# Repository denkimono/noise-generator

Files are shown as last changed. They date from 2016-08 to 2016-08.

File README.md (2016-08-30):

# Entropy in your pocket!

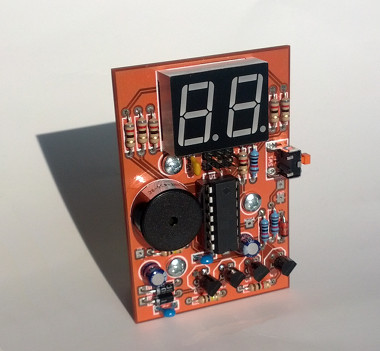
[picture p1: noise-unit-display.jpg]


This is a random number generator but rather than using an algorithm to create only pseudo-random numbers it uses the noise generated by billions of electrons smashing into silicon atoms. This noise is then processed to give a uniform distribution of numbers from 0 to 99 which appears on the display. In addition a speaker on the device enables the noise to be heard. By loading different software onto the device, the numbers can be sent to a computer via a serial link (TTL levels)

## How it works

The noise is generated by applying a reverse voltage to the base-emitter (P-N) junction of a transistor. Normally a P-N junction resists the flow of current in the reverse direction, but if the voltage is high enough then the electrons have enough energy to knock other electrons out of their silicon atoms. These electrons are themselves accelerated by the electric field and knock more electrons out. The process continues and the junction begins to conduct. This effect is called avalanche breakdown.

This generates random voltage fluctuations in the circuit which are amplified and sampled by the microcontroller. Although the noise forms a Gaussian-like distribution of sample values, the probability of an even sample is equal to the probability of an odd sample, so by taking the least significant bits of consecutive samples a flat (uniform) distribution of values can be obtained.

The device is designed to run off a PP3 9V battery (not included).

## How to build it

The file 'bom.txt' contains the parts list and a link to buy them (although these aren't the only sources of these components)

The folder 'gerber' contains all the CAD files you need to make the PCB - just send them off to your favourite board house!

The folder 'code' contains the software to be loaded on to the microcontroller. Type 'make' to build and 'make program' to load it onto the microcontroller using avrdude.

The file 'assembly-instructions.pdf' tells you how to put it together.

Example video of the finished article here:

Noise generator demo (https://www.youtube.com/watch?v=ZSrrZK398-U)

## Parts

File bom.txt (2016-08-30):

1 x PP3 battery holder (flying leads)
https://www.rapidonline.com/trupower-bh9va-pp3-battery-holder-with-flying-leads-18-0163

1 x dual 7 segment display 
https://www.rapidonline.com/truopto-osl20561-ira-14-2mm-dual-red-display-anode-100mcd-57-0151

2 x 1N4001 diodes 
https://www.rapidonline.com/diotec-1n4001-rectifier-diode-1a-50v-50-0381

1 x ATTINY44 
https://www.rapidonline.com/atmel-attiny45-20pu-8bit-microcontroller-4k-flash-dil8-73-4350

1 x row of six PCB pins (for the programming interface)
https://www.rapidonline.com/truconnect-single-row-header-36-way-pcb-plug-22-0545

4 x NPN transistors (BC549C)
https://www.rapidonline.com/diotec-bc549c-npn-transistor-to92-0-2a-30v-50-0298

1 x 5.6V zener diode 
https://www.rapidonline.com/trusemi-bzx55c5v6-zener-diode-0-5w-do35-5-6v-47-3854

3 x screws
https://www.rapidonline.com/affix-pozi-pan-head-self-tapping-screws-no-4-6-5mm-pack-of-100-33-3150

1 x button
https://www.rapidonline.com/omron-b3f-3155-6x6mm-6-15mm-260gf-sq-tact-switch-r-a-78-0140

1 x 14 pin DIL socket
https://www.rapidonline.com/truconnect-ds1009-14-at1nx-14pin-dil-socket-7-62mm-no-central-support-tube-of-34-22-0108

3 x 100nF capacitors 
http://uk.farnell.com/multicomp/mcrr50104z5um0050/cap-cer-z5u-100nf-50v-rad/dp/1216445

2 x 10uF capacitors 
http://uk.farnell.com/multicomp/mcmr63v106m6-3x7/cap-alu-elec-10uf-63v-rad/dp/1870986

1 x speaker
http://uk.farnell.com/pro-signal/abt-436-rc/piezo-transducer-pcb/dp/1300026

Resistors all 0.25W 5% carbon film
3 x 10k resistor 
7 x 82R resistor 
2 x 100k resistor 
1 x 1k resistor

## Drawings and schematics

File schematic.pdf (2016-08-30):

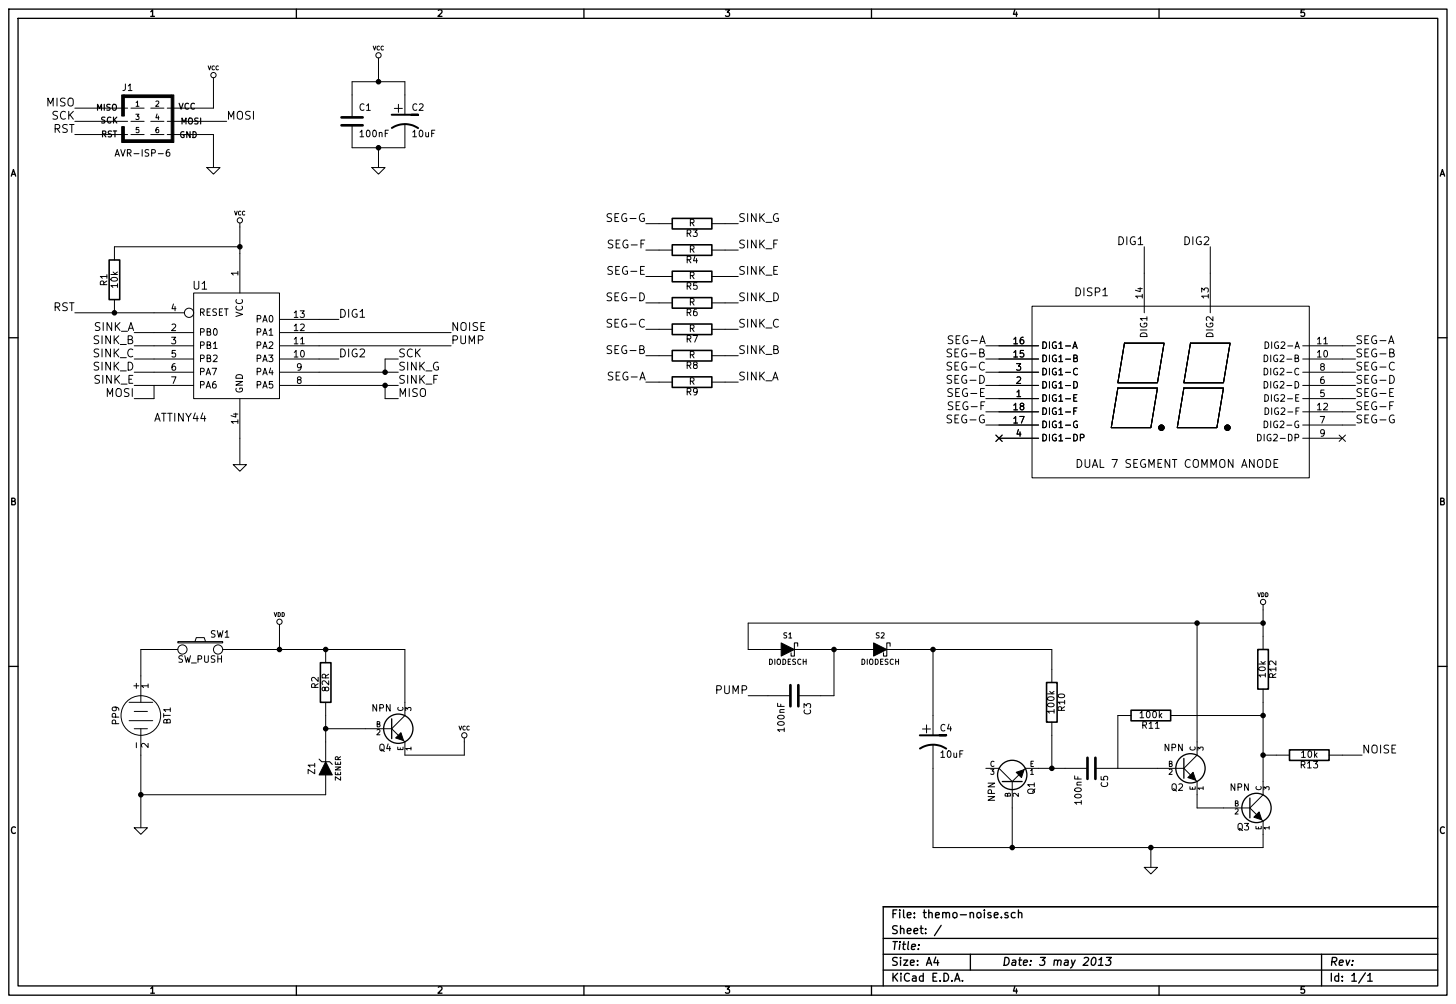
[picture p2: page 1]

DUAL 7 SEGMENT COMMON ANODE

Id: 1/1 Title: File: themo-noise.sch Sheet: / E

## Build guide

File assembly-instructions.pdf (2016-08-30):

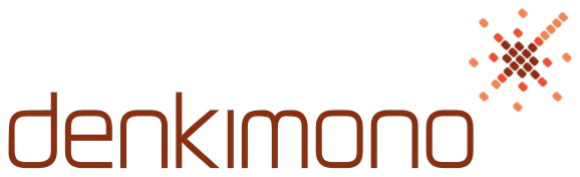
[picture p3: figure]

# Noise generator assembly instructions

Parts list

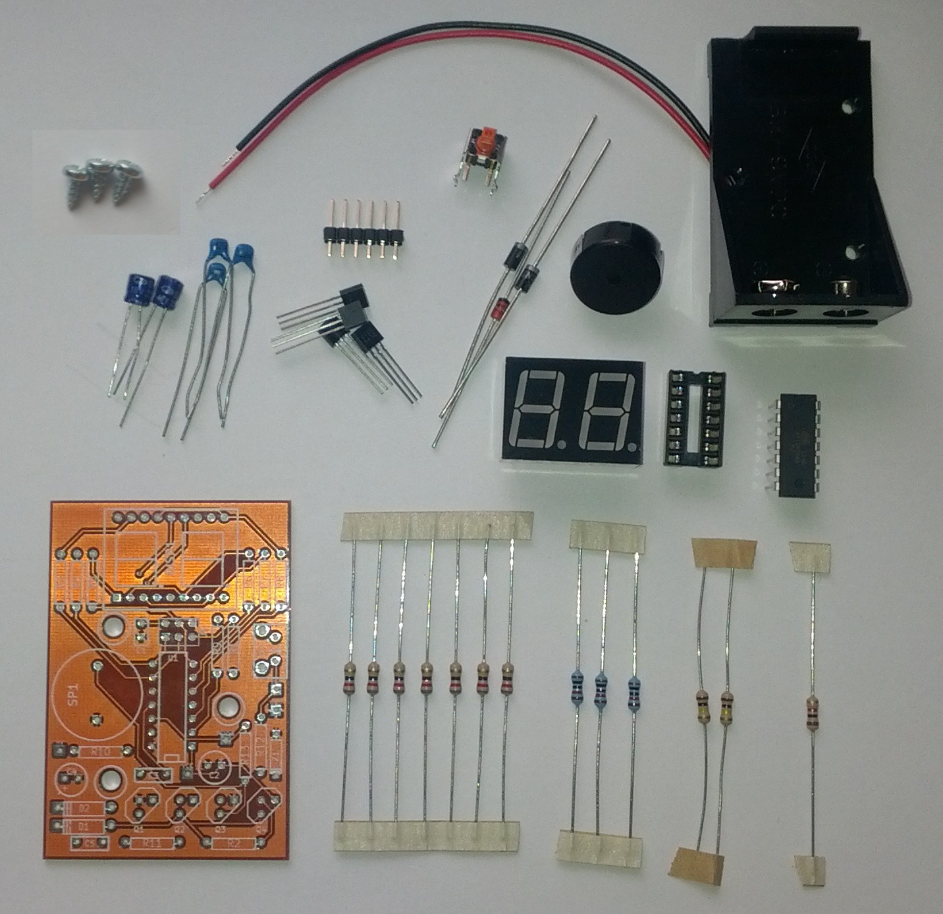
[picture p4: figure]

Check your kit contains the following parts:

1 x PP3 battery holder
3 x 100nF capacitors
2 x 10uF capacitors
2 x 1N4001 diodes
1 x dual 7 segment display 1 x row of six PCB pins
4 x NPN transistors
3 x 10k resistor
7 x 82R resistor

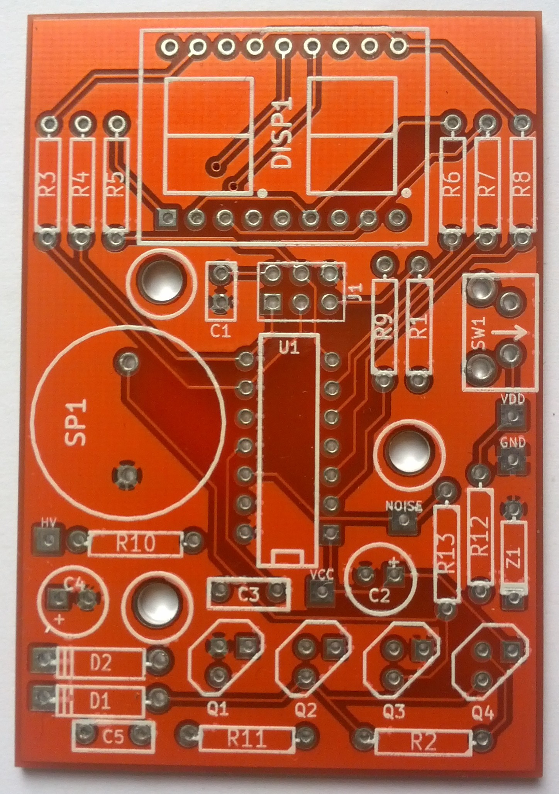
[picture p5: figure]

2 x 100k resistor
1 x 1k resistor
1 x speaker
1 x button
1 x ATTINY44
1 x 14 pin DIL socket
1 x 5.6V zener diode
3 x screws
1 x PCB

## Assembly

1. Fit the 1k resistor R2 (brown black red).
2. Fit the two 100k resistors R11, R10 (brown black yellow).
3. Fit the three 10k resistors R1, R12 and R13 (brown black orange)
4. Fit the seven 82R resistors R3, R4, R5, R6, R7, R8 and R9 (grey red black)
5. Fit the three flat 100nF capacitors C1, C3 and C5.
6. Fit the two round 10uF capacitors C2 and C4. Ensure the negative pin, indicated by the white band on the capacitor, is on the opposite side as the '+' symbol on the PCB silkscreen.
7. Fit the two black 1N4001 diodes D1 and D2. Ensure the white band on the diode is towards the same end as the band on the PCB silkscreen.
8. Fit the 5.6V Zener diode Z1. Ensure the band on the diode is at the same end as the band on the PCB silkscreen.
9. Fit the transistors Q1, Q2, Q3 and Q4. Ensure the flat side of the body of the transistor corresponds with the flat side on the symbol on the PCB silkscreen. The transistors will naturally sit a few millimeters from the surface of the PCB, don't try and force them to sit directly on the PCB.

10.Fit the DIL socket U1. Ensure the notch in the socket is aligned with the notch on the PCB silkscreen (towards the lower edge of the PCB). Make sure the socket is seated correctly by first soldering two diagonally opposite corners of the socket. When the socket is flat on the PCB, solder the remaining pins.

11.Fit the buzzer SP1

12.Fit the display DISP1. Make sure the orientation of the display corresponds with the symbol on the PCB silkscreem with the decimal points to the bottom. Make sure the display is seated correctly by first soldering two diagonally opposite corners of the socket. When the display is flat on the PCB, solder the remaining pins.

13.Fit the button SW1

14.Insert the ATTINY44 into the DIL socket. Make sure the chip is oriented correctly in the socket with the notch on the device facing towards the the notch on the socket (towards the lower edge of the PCB). Make sure that all the pins are seated in the socket properly before gently pressing the chip in to the socket.

15.Solder the red wire of the battery holder to the pad marked '+' on the back of the PCB. Solder the black wire of the battery holder to the pad marked '-' on the back of the PCB. Before screwing the battery holder in to place, test the noise generator by inserting a PP3 battery in to the holder and pressing the button. Make sure the battery is correctly oriented in the holder before pressing the button.

16.If you intend to reprogam the device, fit the PCB pins J1.

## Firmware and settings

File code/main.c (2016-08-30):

#define F_CPU 1000000UL  /* 1 MHz internal oscillator */

#include <avr/io.h>
#include <avr/wdt.h>
#include <avr/interrupt.h>
#include <avr/sleep.h>
#include <inttypes.h>
#include <util/delay.h>
#include <avr/pgmspace.h>
#include <stdlib.h>
#include <stdio.h>
#include <math.h>

#define TRUE	1
#define FALSE	0

#define BATTERY_THRESHOLD	70 // reduce this if you get the "bL" display with a good battery 

#define ENABLE_A(line)	PORTA |= line
#define DISABLE_A(line)	PORTA &= ~line
#define ENABLE_B(line)	PORTB |= line
#define DISABLE_B(line)	PORTB &= ~line

// IO

// DISPLAY
#define SEG_A  _BV(PB0)
#define SEG_B  _BV(PB1)
#define SEG_C  _BV(PB3)
#define SEG_D  _BV(PB2)

#define SEG_E  _BV(PA7)
#define SEG_F  _BV(PA6)
#define SEG_G  _BV(PA5)
#define SEG_DP _BV(PA4)

#define DIG_2  _BV(PA3)
#define DIG_1  _BV(PA0)

// misc
#define PUMP  _BV(PA2)
#define TX	  _BV(PA5)

// display modes
#define DISPLAY_ANIMATION	0
#define DISPLAY_DIGIT		1
#define DISPLAY_BATTERY		2

// voltage booster stuff
volatile unsigned char pump_toggle=0;

// display stuff
volatile unsigned char display_on=FALSE;
volatile char screen_display_value=0;
volatile unsigned char current_digit=0;
volatile unsigned char display_mode=DISPLAY_ANIMATION;

// random number stuff
volatile char bitcount=0;
volatile unsigned char random_byte=0;
volatile unsigned char max_adc=0;
volatile char got_byte=FALSE;

// digit bit patterns
const unsigned char digits[] PROGMEM =
{
	0x10,// 0 - b'0001 0000'
	0xf1,// 1 - b'1111 0001'*
	0x24,// 2 - b'0010 0100'*
	0x60,// 3 - b'0110 0000'*
	0xc1,// 4 - b'1100 0001'*
	0x42,// 5 - b'0100 0010'
	0x02,// 6 - b'0000 0010'*
	0xf8,// 7 - b'1111 1000'*
	0x00,// 8 - b'0000 0000'*
	0x40,// 9 - b'0100 0000'
	0xef, // '-' - b'1011 1111'
	0xff, // ' ' - b'1111 1111'*
};

#define LED_DASH	0x0A
#define LED_BLANK	0x0B
#define LED_L		0x1f// 'L' - b'0001 1011'
#define LED_B		0x0b// 'b' - b'0000 1011'

// animation bit patterns
const unsigned char spinner[] PROGMEM =
{
	0xfe,// b'1111 1110'
	0xfd,// b'1111 1101'
	0xfb,// b'1111 1011'
	0x7f,// b'0111 1111'
	0xbf,// b'1011 1111'
	0xdf,// b'1101 1111'
};
#define FRAMES	0x06

void set_segments(unsigned char pattern)
{
	// set new display value
	PORTB&=0xF0;
	PORTB|=pattern&0x0F;

	PORTA&=0x0F;
	PORTA|=pattern&0xF0;
}

// display the appropriate 'numeral' on 'digit'
void display_digit(unsigned char numeral,char digit)
{
	// clear display
	DISABLE_A(DIG_1);
	DISABLE_A(DIG_2);
	
	// get digit bit pattern (will fail if numeral is >9 or <0)
	unsigned char pattern = pgm_read_byte(&digits[numeral]);
	
	// set new display value
	set_segments(pattern);
	
	// enable digit
	ENABLE_A(digit);
}

void display_multiplexer(void)
{
	if(display_on==FALSE)
	{
		// clear display
		DISABLE_A(DIG_1);
		DISABLE_A(DIG_2);
		return;
	}
	
	// display multiplexer

	if(display_mode==DISPLAY_DIGIT)
	{
		// handle out of range
		if(screen_display_value>99 || screen_display_value<-9)
		{
			display_digit(LED_DASH,current_digit?DIG_1:DIG_2);
			current_digit=~current_digit;
			return;
		}

		if(current_digit)
		{
			if(screen_display_value>=0)
			{
				// suppress leading zero
				if(screen_display_value>=10)
					display_digit(screen_display_value/10,DIG_1);
				else
					display_digit(LED_BLANK,DIG_1);
			}
			else// show minus
			{
				display_digit(LED_DASH,DIG_1);
			}
		}
		else
		{
			if(screen_display_value>=0)
			{
				display_digit(screen_display_value%10,DIG_2);
			}
			else
			{
				if(screen_display_value>=-9)
				{
					display_digit(abs(screen_display_value)%10,DIG_2);
				}
			}
		}
	}

	if(display_mode==DISPLAY_ANIMATION)
	{
		// clear display
		DISABLE_A(DIG_1);
		DISABLE_A(DIG_2);
		
		// set new display value
		set_segments(screen_display_value);
	
		// enable digit
		ENABLE_A(current_digit?DIG_1:DIG_2);
	}
	
	if(display_mode==DISPLAY_BATTERY)
	{
		// clear display
		DISABLE_A(DIG_1);
		DISABLE_A(DIG_2);

		if(current_digit)
			set_segments(LED_B);
		else
			set_segments(LED_L);

		// enable digit
		ENABLE_A(current_digit?DIG_1:DIG_2);
	}
	
	current_digit=~current_digit;
}

// multiplexer interrupt
ISR(TIM0_COMPA_vect)
{
	display_multiplexer();
	
	if(pump_toggle&0x01)
		ENABLE_A(PUMP);
	else
		DISABLE_A(PUMP);
		
	pump_toggle++;
}

// ADC complete interrupt
ISR(ADC_vect)
{
	unsigned char val=(unsigned char)ADCH;

	// for battery/system self check
	if(max_adc<val)
		max_adc=val;

	// avoid limits (ADC is clipping)
	if(val<255 && val>0)
	{
		// take a bit
		random_byte<<=1;
		random_byte|=(0x01&val)!=0?1:0;
		bitcount++;

		if(bitcount>=8)
		{
			bitcount=0;
			got_byte=TRUE;
		}
		else
		{
			// start another conversion
			ADCSRA |= (1 << ADSC);
		}
	}
	else
	{
		// start another conversion
		ADCSRA |= (1 << ADSC);
	}
	_delay_ms(1);
}

#define SERIAL_DELAY 100 // 9600
void transmit_byte(unsigned int byte)
{
	int n;

	cli();

	// start bit
	DISABLE_A(TX);
	_delay_us(SERIAL_DELAY);
	
	for(n=0;n<8;n++)
	{
		if(!(byte&0x01))
		{
			DISABLE_A(TX);
		}
		else
		{
			ENABLE_A(TX);
		}
		byte>>=1;
		
		_delay_us(SERIAL_DELAY);
	}

	// stop bit
	ENABLE_A(TX);
	_delay_us(SERIAL_DELAY);

	sei();

}

void send_serial_byte(unsigned char byte)
{
	char buffer[7];
	char *ptr=buffer;

	buffer[2]=byte%10+'0';
	byte/=10;
	buffer[1]=byte%10+'0';
	byte/=10;
	buffer[0]=byte%10+'0';

//	buffer[3]=',';
	buffer[3]=0x0d;
	buffer[4]=0x0a;
	buffer[5]=0;

	while(*ptr!=0)
	{
		transmit_byte(*ptr);
		ptr++;
	}
}

int main (void)
{
	wdt_disable();

	TCCR0A = (1<<WGM01);  // Mode = CTC
	
	// set timer0 prescaler
	TCCR0B = (1<<CS01);// TIMER0 = FCPU/8
	
	//initialize Counter
	TCNT0=0;
	
	// set counter compare value
	OCR0A=100;
	
	// enable output compare interrupt (enable multiplexer)
	TIMSK0=(1<<OCIE1A);

	// set up i/o pins
    DDRA = SEG_E|SEG_F|SEG_G|SEG_DP|DIG_1|DIG_2|PUMP;
    DDRB = SEG_A|SEG_B|SEG_C|SEG_D;

	// setup ADC
	
	// ADC reference voltage (set to VCC)
	ADMUX =0;//(1 << REFS1); 

	// select ADC channel (ADC1)
	ADMUX |=(1<<MUX0);
	
	// only take 8-bit resolution (read ADCH)
	ADCSRB |= (1 << ADLAR); 

	// ADC clock prescaler
	ADCSRA |= (1 << ADPS1) | (1 << ADPS0); 

	// enable ADC interupt
	ADCSRA |= (1 << ADIE); 

	// enable ADC hardware
	ADCSRA |= (1 << ADEN); 

	// start ADC conversion
	ADCSRA |= (1 << ADSC);

	// enable interrupts
	sei();

/*
	// test serial TX - send random numbers to port at 9600bps
	while(1)
	{
			do
			{
				// start ADC conversion
				got_byte=FALSE;
				ADCSRA |= (1 << ADSC);
				while(got_byte==FALSE);
			}
			while(random_byte>=100);
//			while(random_byte==0 || random_byte==255);
			
			send_serial_byte(random_byte);

	}
*/
	display_on=TRUE;
	unsigned char frame=0;
	char spins=3;

	display_digit(LED_BLANK,DIG_1);
	display_digit(LED_BLANK,DIG_2);

	// do start animation, give charge pump time to pump up
	while(spins>0)
	{
		screen_display_value=pgm_read_byte(&spinner[frame]);
		
		frame++;

		if(frame%FRAMES==0)
		{
			frame%=FRAMES;
			spins--;
		}

		_delay_ms(25);
	}
	display_on=FALSE;

	// check the battery by checking a few numbers
	max_adc=0;
	char count=50;
    while(count)
    {
		while(got_byte==FALSE);
		count--;
		got_byte=FALSE;
		// start ADC conversion again
		ADCSRA |= (1 << ADSC);
	}
	
	// see if max_adc looks sensible
	if(max_adc<BATTERY_THRESHOLD)
	{
		display_mode=DISPLAY_BATTERY;
		display_on=TRUE;
		while(1);
	}

    while(1)
    {
		_delay_ms(10);
		
		if(got_byte==TRUE)
		{
			got_byte=FALSE;
			
			if(random_byte<100 && random_byte>=0)
			{
				display_mode=DISPLAY_DIGIT;
				screen_display_value = random_byte;

				//send_serial_byte(random_byte);
				//transmit_byte(random_byte);

				//enable display
				display_on=TRUE;
				
				// time out after 10 seconds and go to sleep
				int i;
				for(i=0;i<10;i++)
				{
					_delay_ms(1000);
				}

				// turn everything off
				DISABLE_A(DIG_1);
				DISABLE_A(DIG_2);
				set_sleep_mode(SLEEP_MODE_PWR_DOWN);
				sleep_enable();
				cli();
				// night night
				sleep_cpu();

				while(1);
			}

			// start ADC conversion again
			ADCSRA |= (1 << ADSC);
		}
		else
		{
			// taken too long, battery is probably failing
			display_mode=DISPLAY_BATTERY;
			display_on=TRUE;
			while(1);
		}
		
   }
}
